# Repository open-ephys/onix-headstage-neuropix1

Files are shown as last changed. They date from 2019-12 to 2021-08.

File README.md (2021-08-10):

# ONIX Neuropixels-1.0 Headstage
Serialized, multifunction headstage targeting the [Neuropixels 1.0
probe](https://www.neuropixels.org/probe). This headstage supports:

- Two Neuropixels 1.0 probes
- A BNO055 9-axis IMU for real-time, 3D orientation tracking
- Three TS4231 light to digital converters for real-time, 3D position tracking
  with HTC Vive base stations
- A high performance MAX10 FPGA for real-time processing and probe data
  correction (offset removal and gain correction)

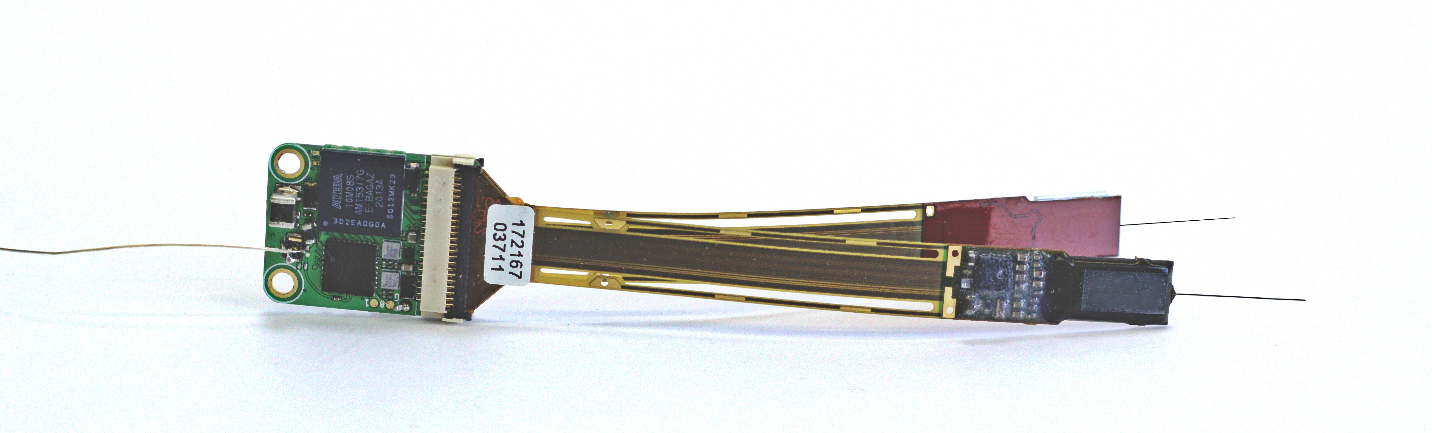
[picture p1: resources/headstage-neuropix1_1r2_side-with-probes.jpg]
headstage-neuropix1 revision 1.2


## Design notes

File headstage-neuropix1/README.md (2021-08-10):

# Design Files

## Standard vs.large
There are two versions of this headstage in this repository, one that uses the
standard IMEC-specified ZIF connector and a second that uses a larger, more
reliable one.

## Production
This folder contains panelized versions of both designs.

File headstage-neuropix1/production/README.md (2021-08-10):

# Production Files
These files are panelized versions of both large and standard ZIF connector
variants of the Neuropixels 1.0 Headstage. They were provided by [Speedy
Circuits](https://www.speedy-circuits.com.tw/).

- TOP, L#, BOT: Copper layers
- VIP: Via in pad
- PTH: Plated through hole
- NPTH: Non-plated through hole
- OUT: Outline
- \*SILK: Silkscreen
- \*PASTE: Stencil

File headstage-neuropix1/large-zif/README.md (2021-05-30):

# headstage-neuropix (large ZIF)
This version of the headstage has a larger, more reliable ZIF connector.

## Bill of materials
The bill of materials is located here: https://docs.google.com/spreadsheets/d/1dWKHe0VTVimXe6pwDThY2RrQNF4wLWle7LTdl6iC_KU/edit?usp=sharing

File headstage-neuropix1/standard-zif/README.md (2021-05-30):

# headstage-neuropix (standard ZIF)
This version of the headstage uses the IMEC-specified ZIF connector.

## Bill of materials
The bill of materials is located here: https://docs.google.com/spreadsheets/d/1dWKHe0VTVimXe6pwDThY2RrQNF4wLWle7LTdl6iC_KU/edit?usp=sharing

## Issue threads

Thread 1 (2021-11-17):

MAX4945 might be the wrong choice for this design

jonnew, 2021-11-17:
MAX4945 is an under/overvoltage lockout circuit used to protect the headstage. It turns on with the range 4.15 to 5.8V, which seems perfect. But there is an interesting issue that occurs when using a long and thin tether. Because of the series resistance of the tether, the voltage under no load needs to be quite high (e.g. like 7.5V). This way when the headstage starts to draw current and voltage is dropped on the tether, it settles at 5 or so volts at the headstage input. However, when using the MAX4945, 7.5V is too high for the headstage to ever turn on and we enter a deadlock. Choosing a version of this chip with a much wider range is probably a good idea (e.g. MAX4943 which has 7.4V overvoltage lockout) or it might just need to be bypassed. Alternatively, lower DC resistance tethers can be used (e.g. like the ones on the miniscope).

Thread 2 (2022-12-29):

Incompatibility between Photodiode index 0 and address 256

filcarv, 2022-12-29:
Photodiode 0 doesn't work reliably when using the NP in the nearest socket.

I don't see users using two probes with free-moving animals, so we can tell users to use the other socket for freely-moving animals.

This table of tests shows that Photodiode 0 (PD0) doesn't work reliably for some scenarios.

|Plugged<br />257 | Plugged<br />256 | Stream<br />257 | Stream<br />256 | Bonsai<br />257 | Bonsai<br />256 | PD0
|-- | -- | -- | -- | -- | -- | --
|Yes | Yes | True | - | Enabled | Disabled | ✅
|Yes | - | True | - | Enabled | Disabled | ✅
|- | Yes | - | True | Disabled | Enabled | 🗑️
|Yes | Yes | True | False | Enabled | Enabled | 🗑️

🗑️ - The data is garbage, and can’t be trusted. It still sends events even if the IR is not present.

jonnew, 2022-12-30:
Thanks for the detailed report. This behavior is similar to an issue on the headstage-64 rev. 1.3 where the routing of the un-amplified photodiode (PD) signal passes under the BNO055 and is corrupted in the process. Even in revision 1.3b, where the PD traces pass under the BNO055 on a different layer, with ground plane in between the them and the BNO055, it does not function. These traces are obviously very sensitive to stray electric fields from digital processes around them. I have a feeling that some of the traces coming back from the neuropixels' parallel-serial bus (PSB) are doing exactly the same thing. This makes sense given that the TS4231 receiver is quite far from the PD. If we redesign this headstage, extreme caution will be used when laying out the un-amplified PD  traces. Further, a guard ring can be employed to prevent leakage currents through the solder-mask.

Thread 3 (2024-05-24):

Gateware issues

jonnew, 2024-05-24:
Testing of these devices seems to be revealing intermittent issues in the gateware:

1. One channel in 384 of both the LFP and Spike streams always seems to produce 0 values. This value appears in the first frame of a superframe, but its position changes between resets. Aside from the obviously incorrect value, the location switch leads to a lack of confidence in a consistent channel mapping between runs
2. The hub clock is placed at the end of the frame which is at least non-conventional
3. The sync words are included in the data frame, but are not used
4. The amplifier data is non-contiguous and should be reordered in the gateware to remove counter and reserved segments
5. The Q11.5 -> Q11 conversion should be done on the FPGA instead of packing fixed point values into the frame for no reason (10 bit ADC determines sample resolution, the extra 5 bits are useless)

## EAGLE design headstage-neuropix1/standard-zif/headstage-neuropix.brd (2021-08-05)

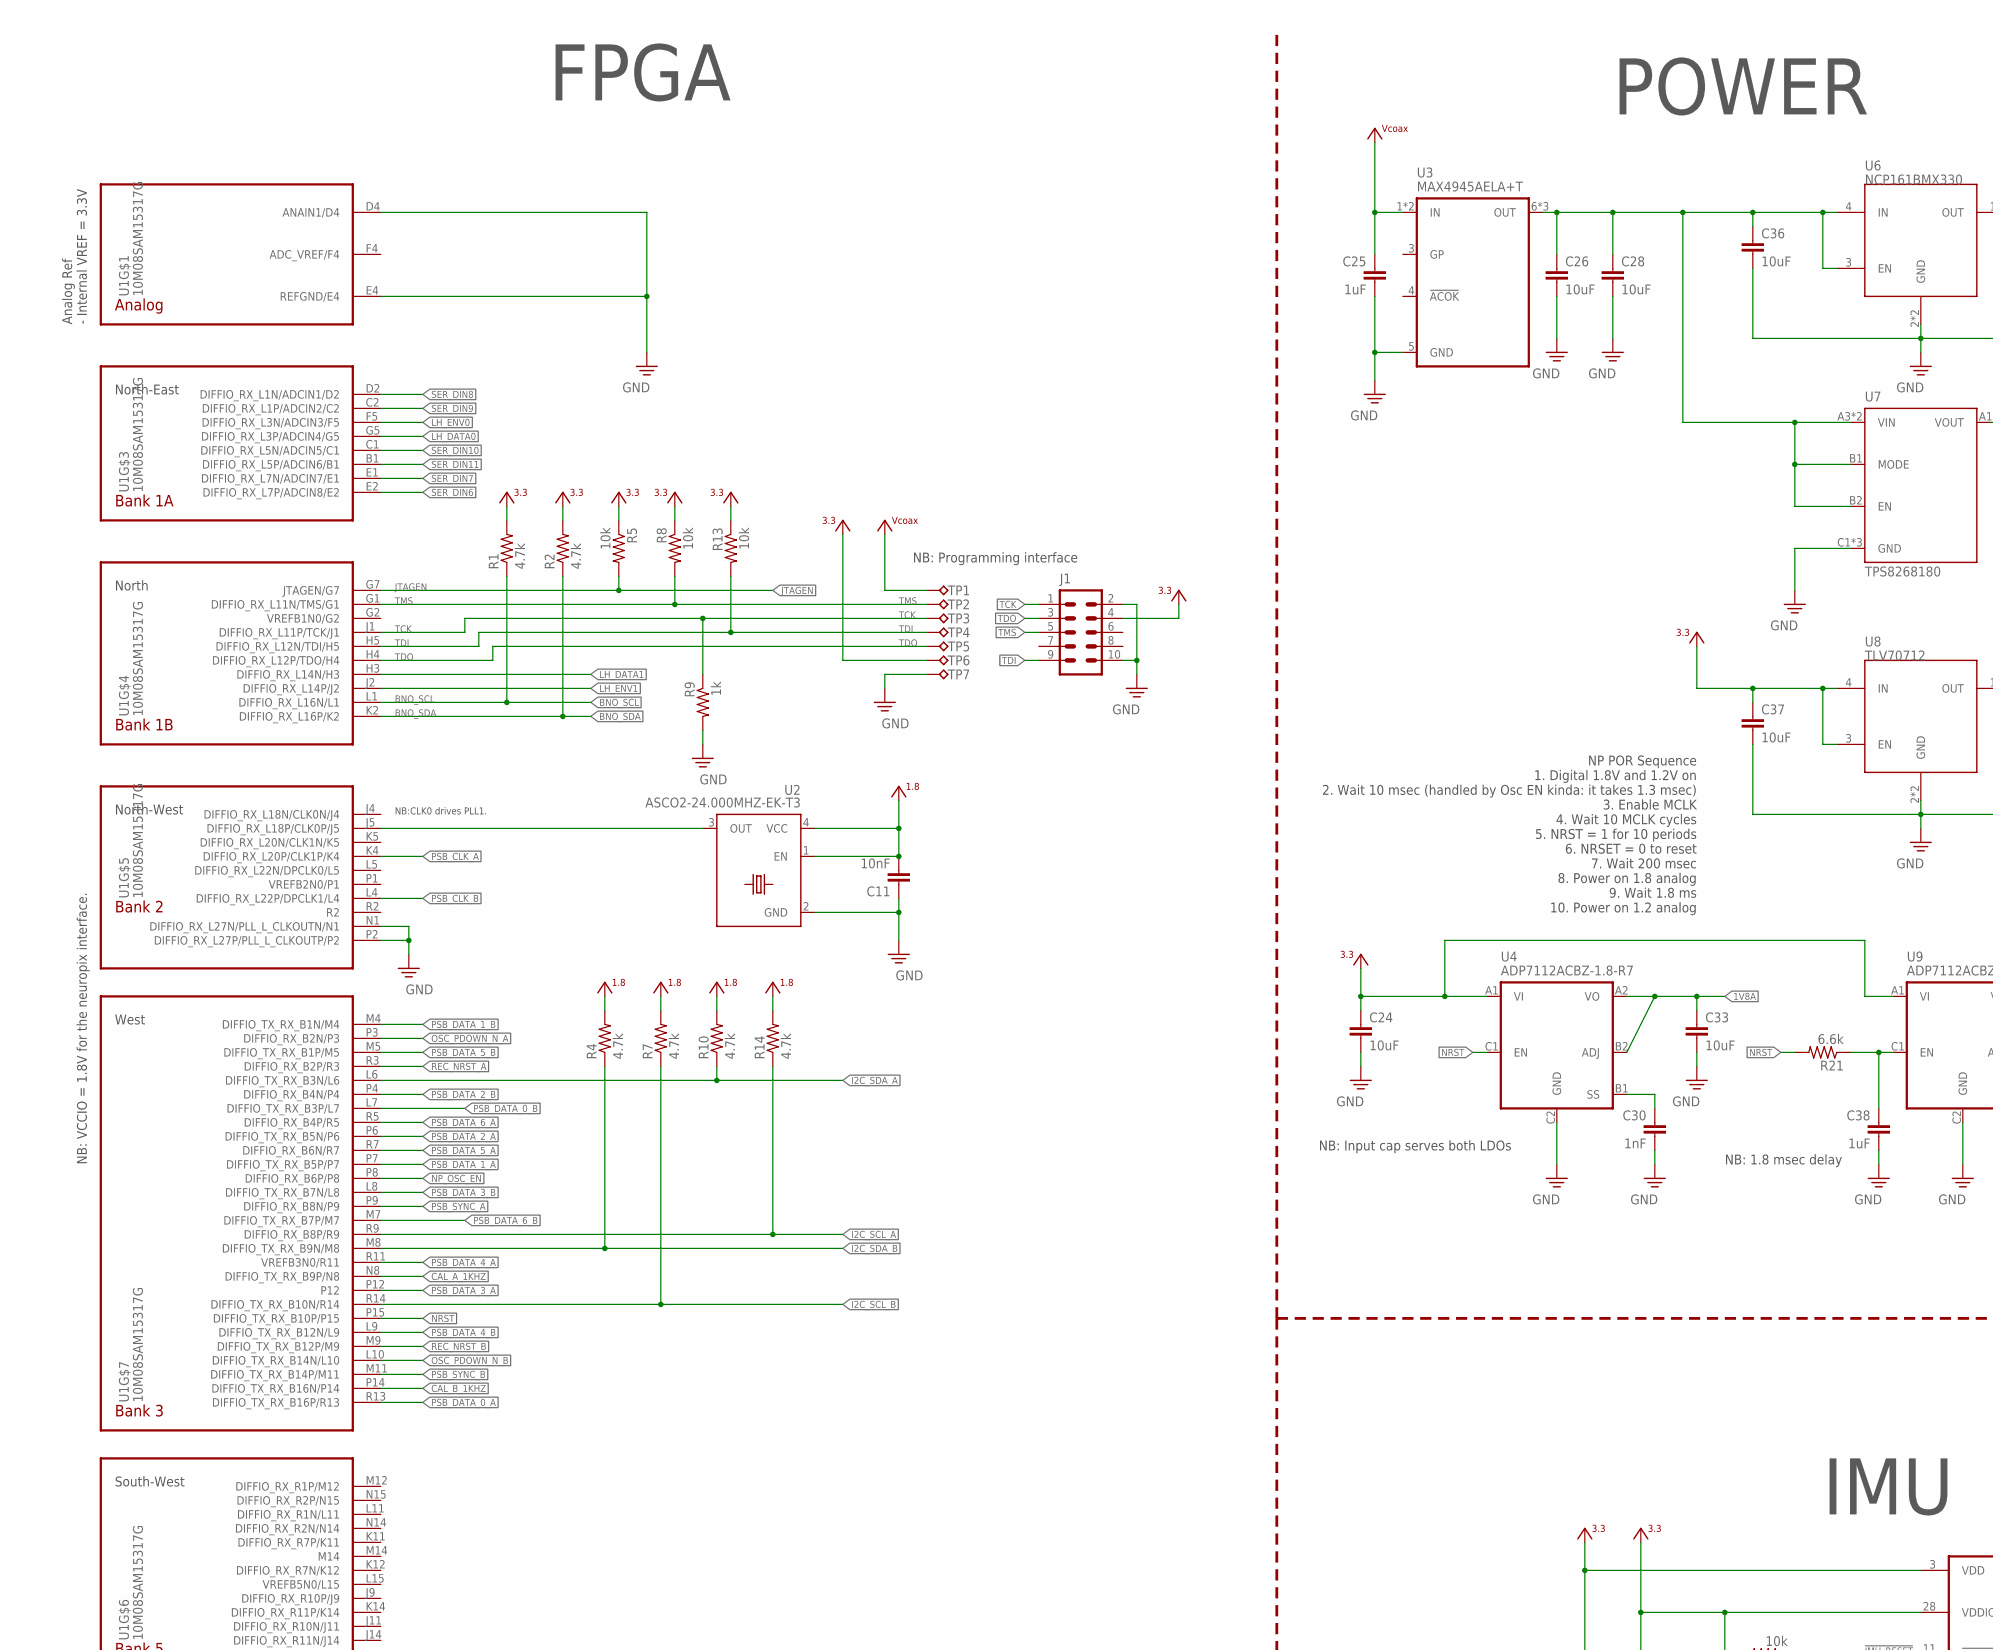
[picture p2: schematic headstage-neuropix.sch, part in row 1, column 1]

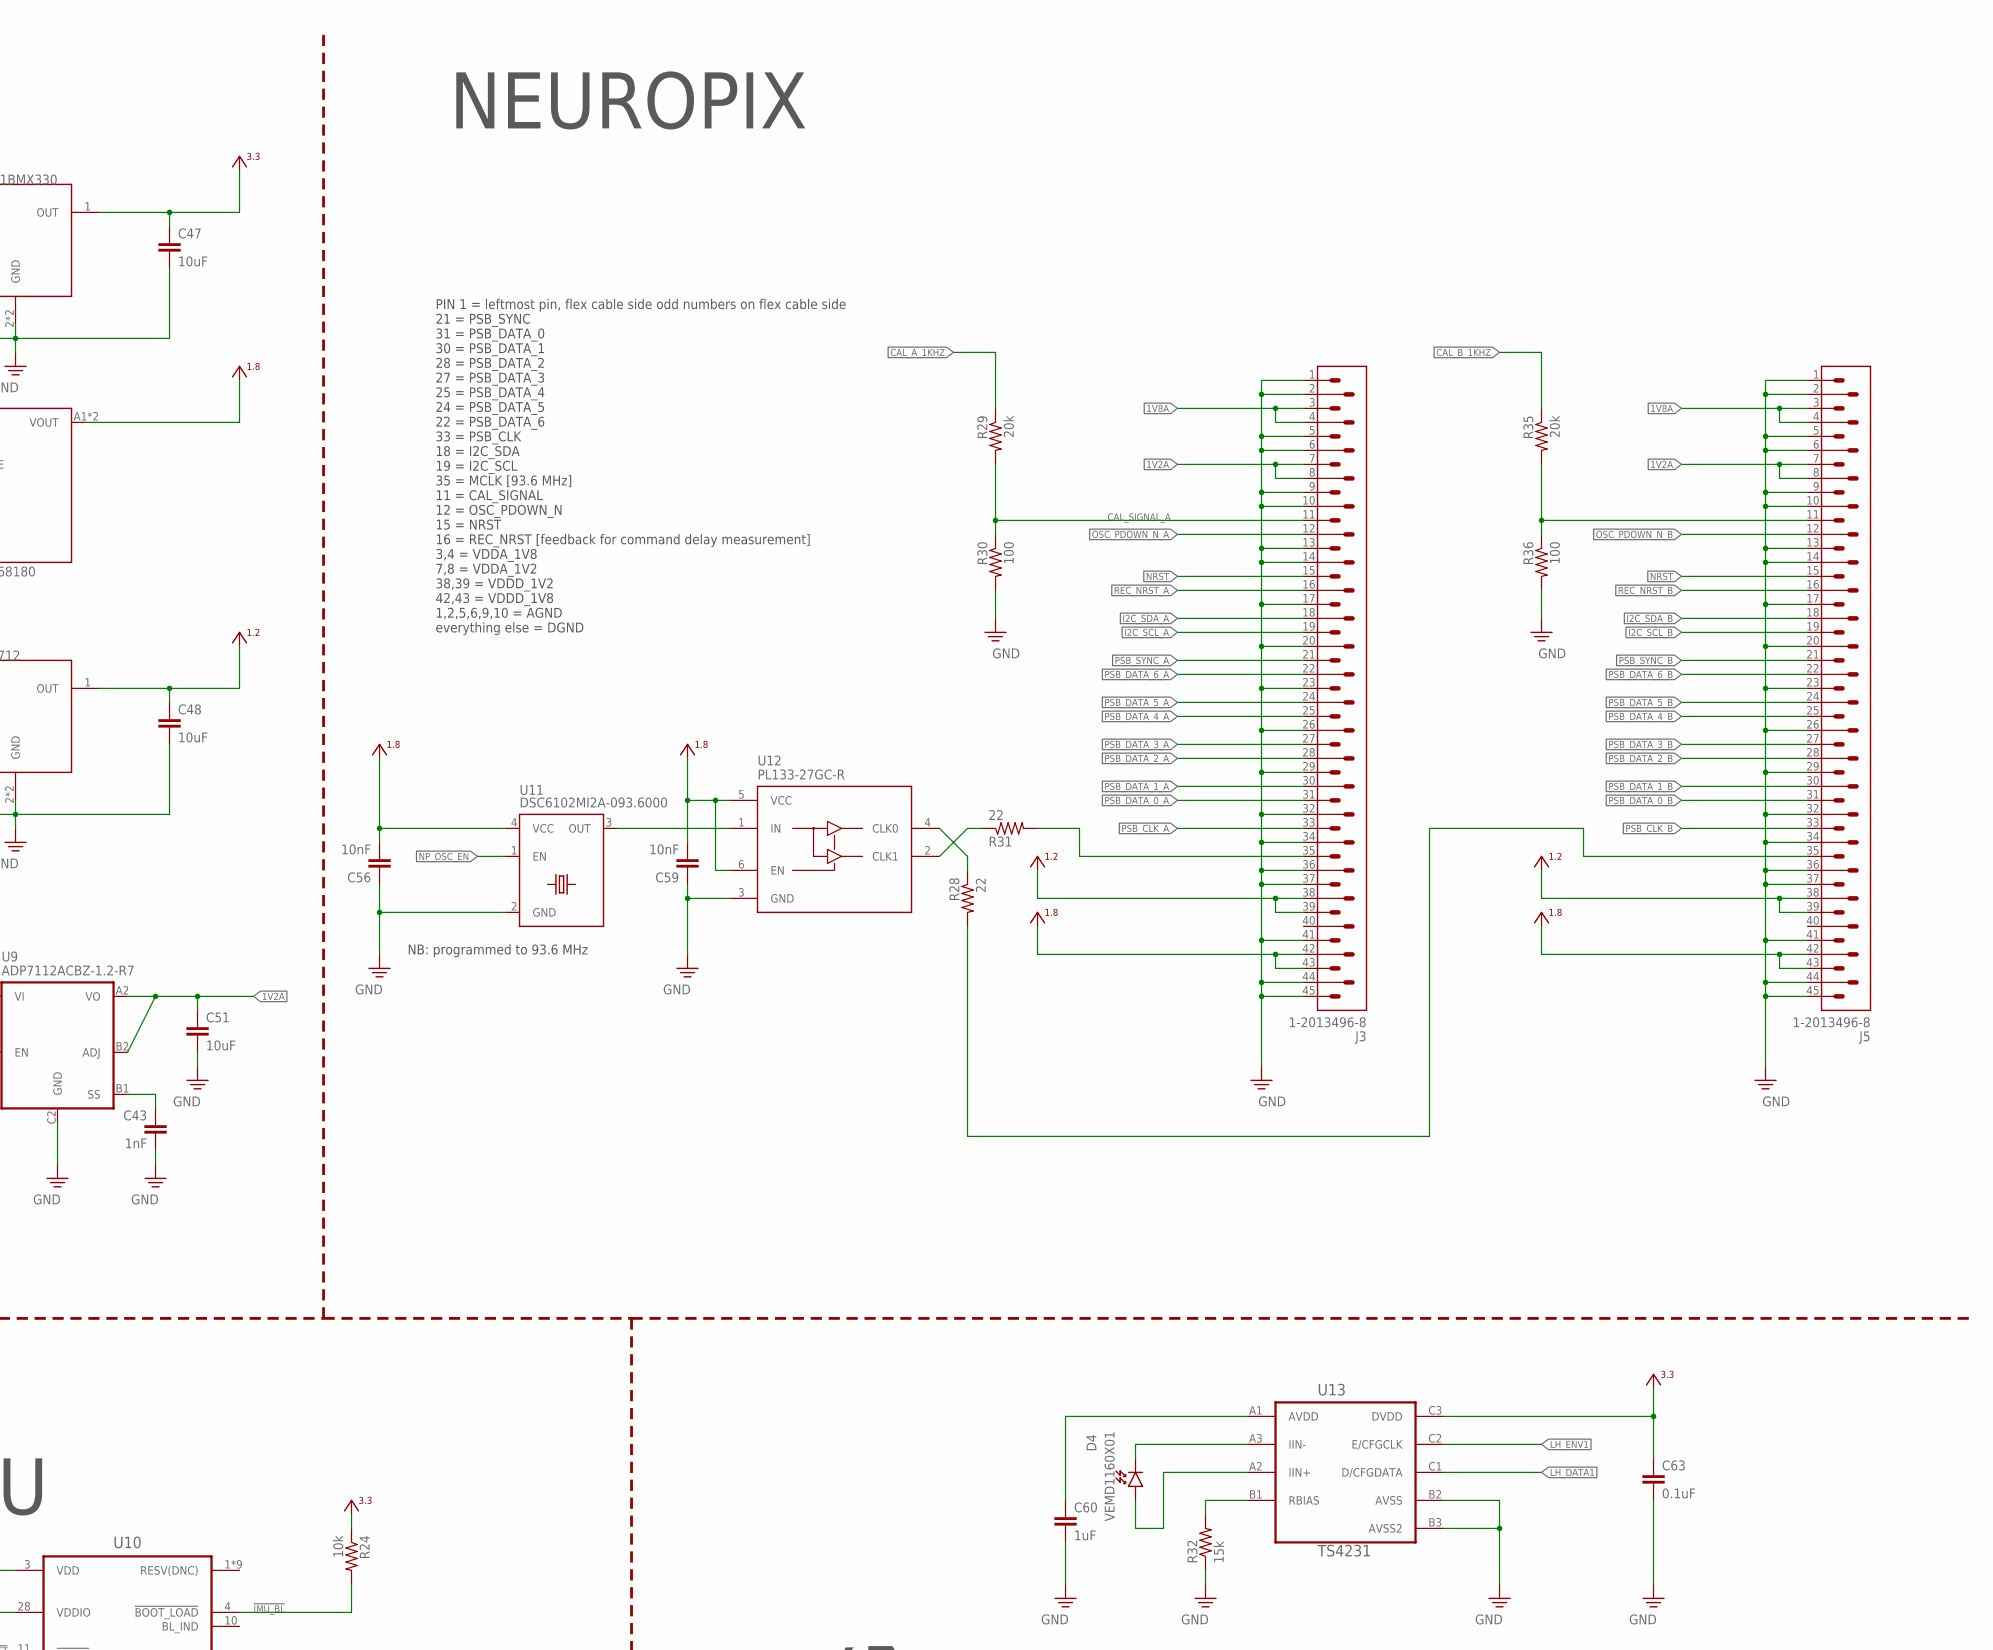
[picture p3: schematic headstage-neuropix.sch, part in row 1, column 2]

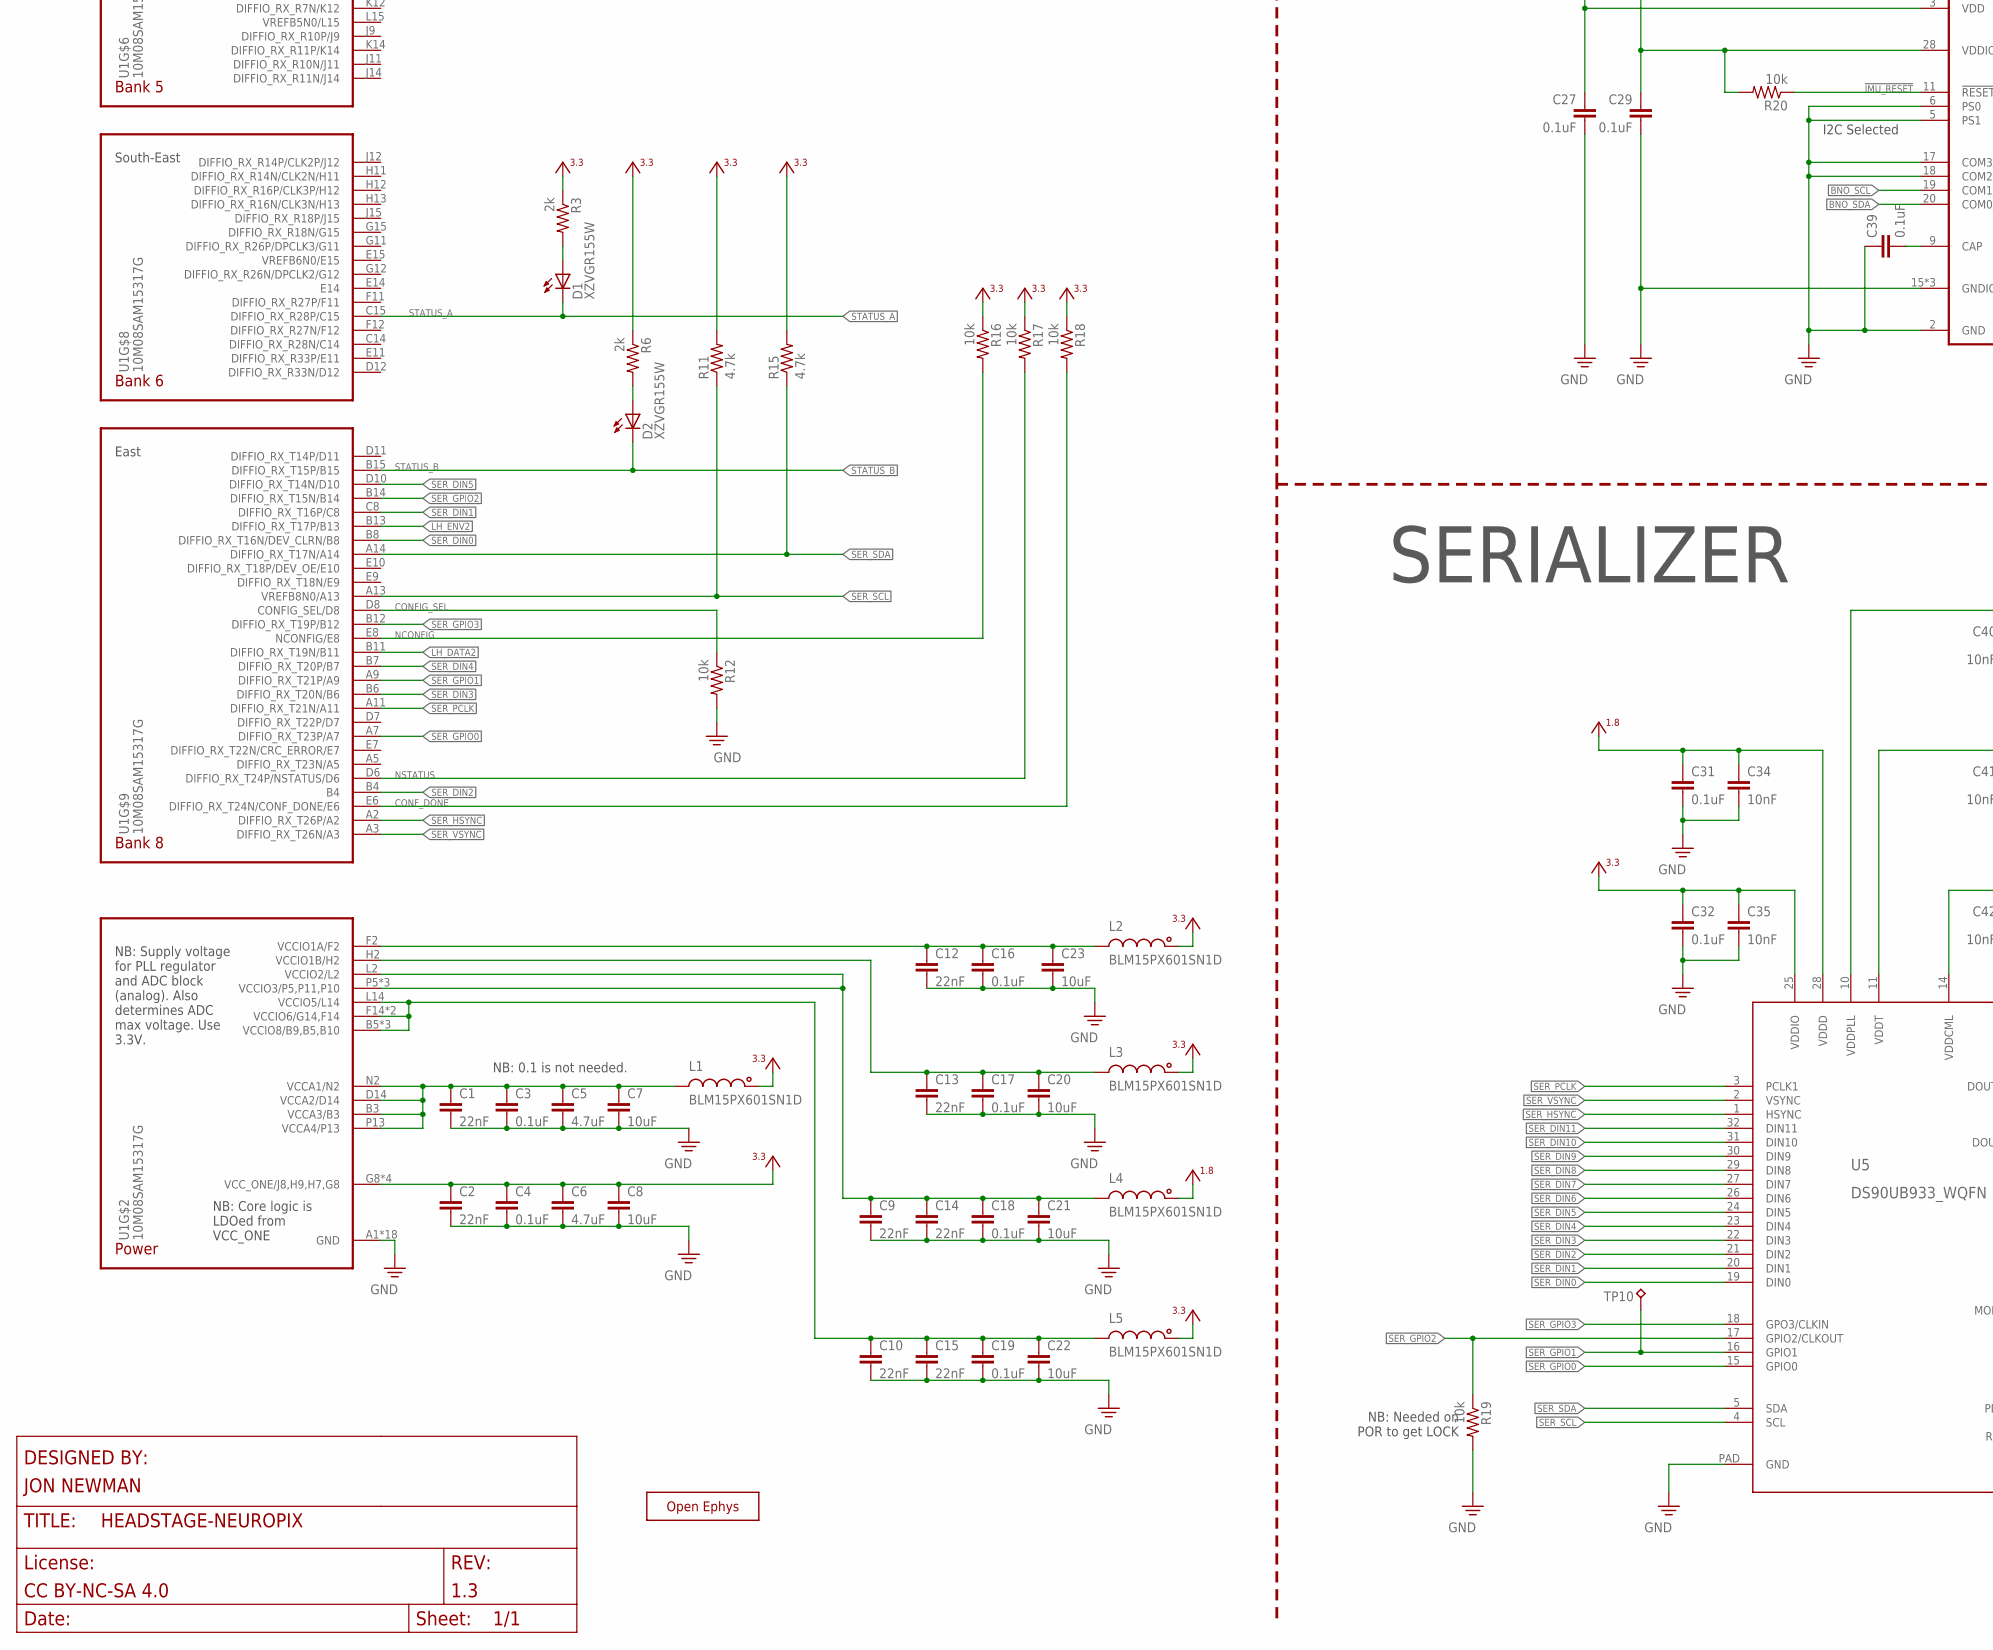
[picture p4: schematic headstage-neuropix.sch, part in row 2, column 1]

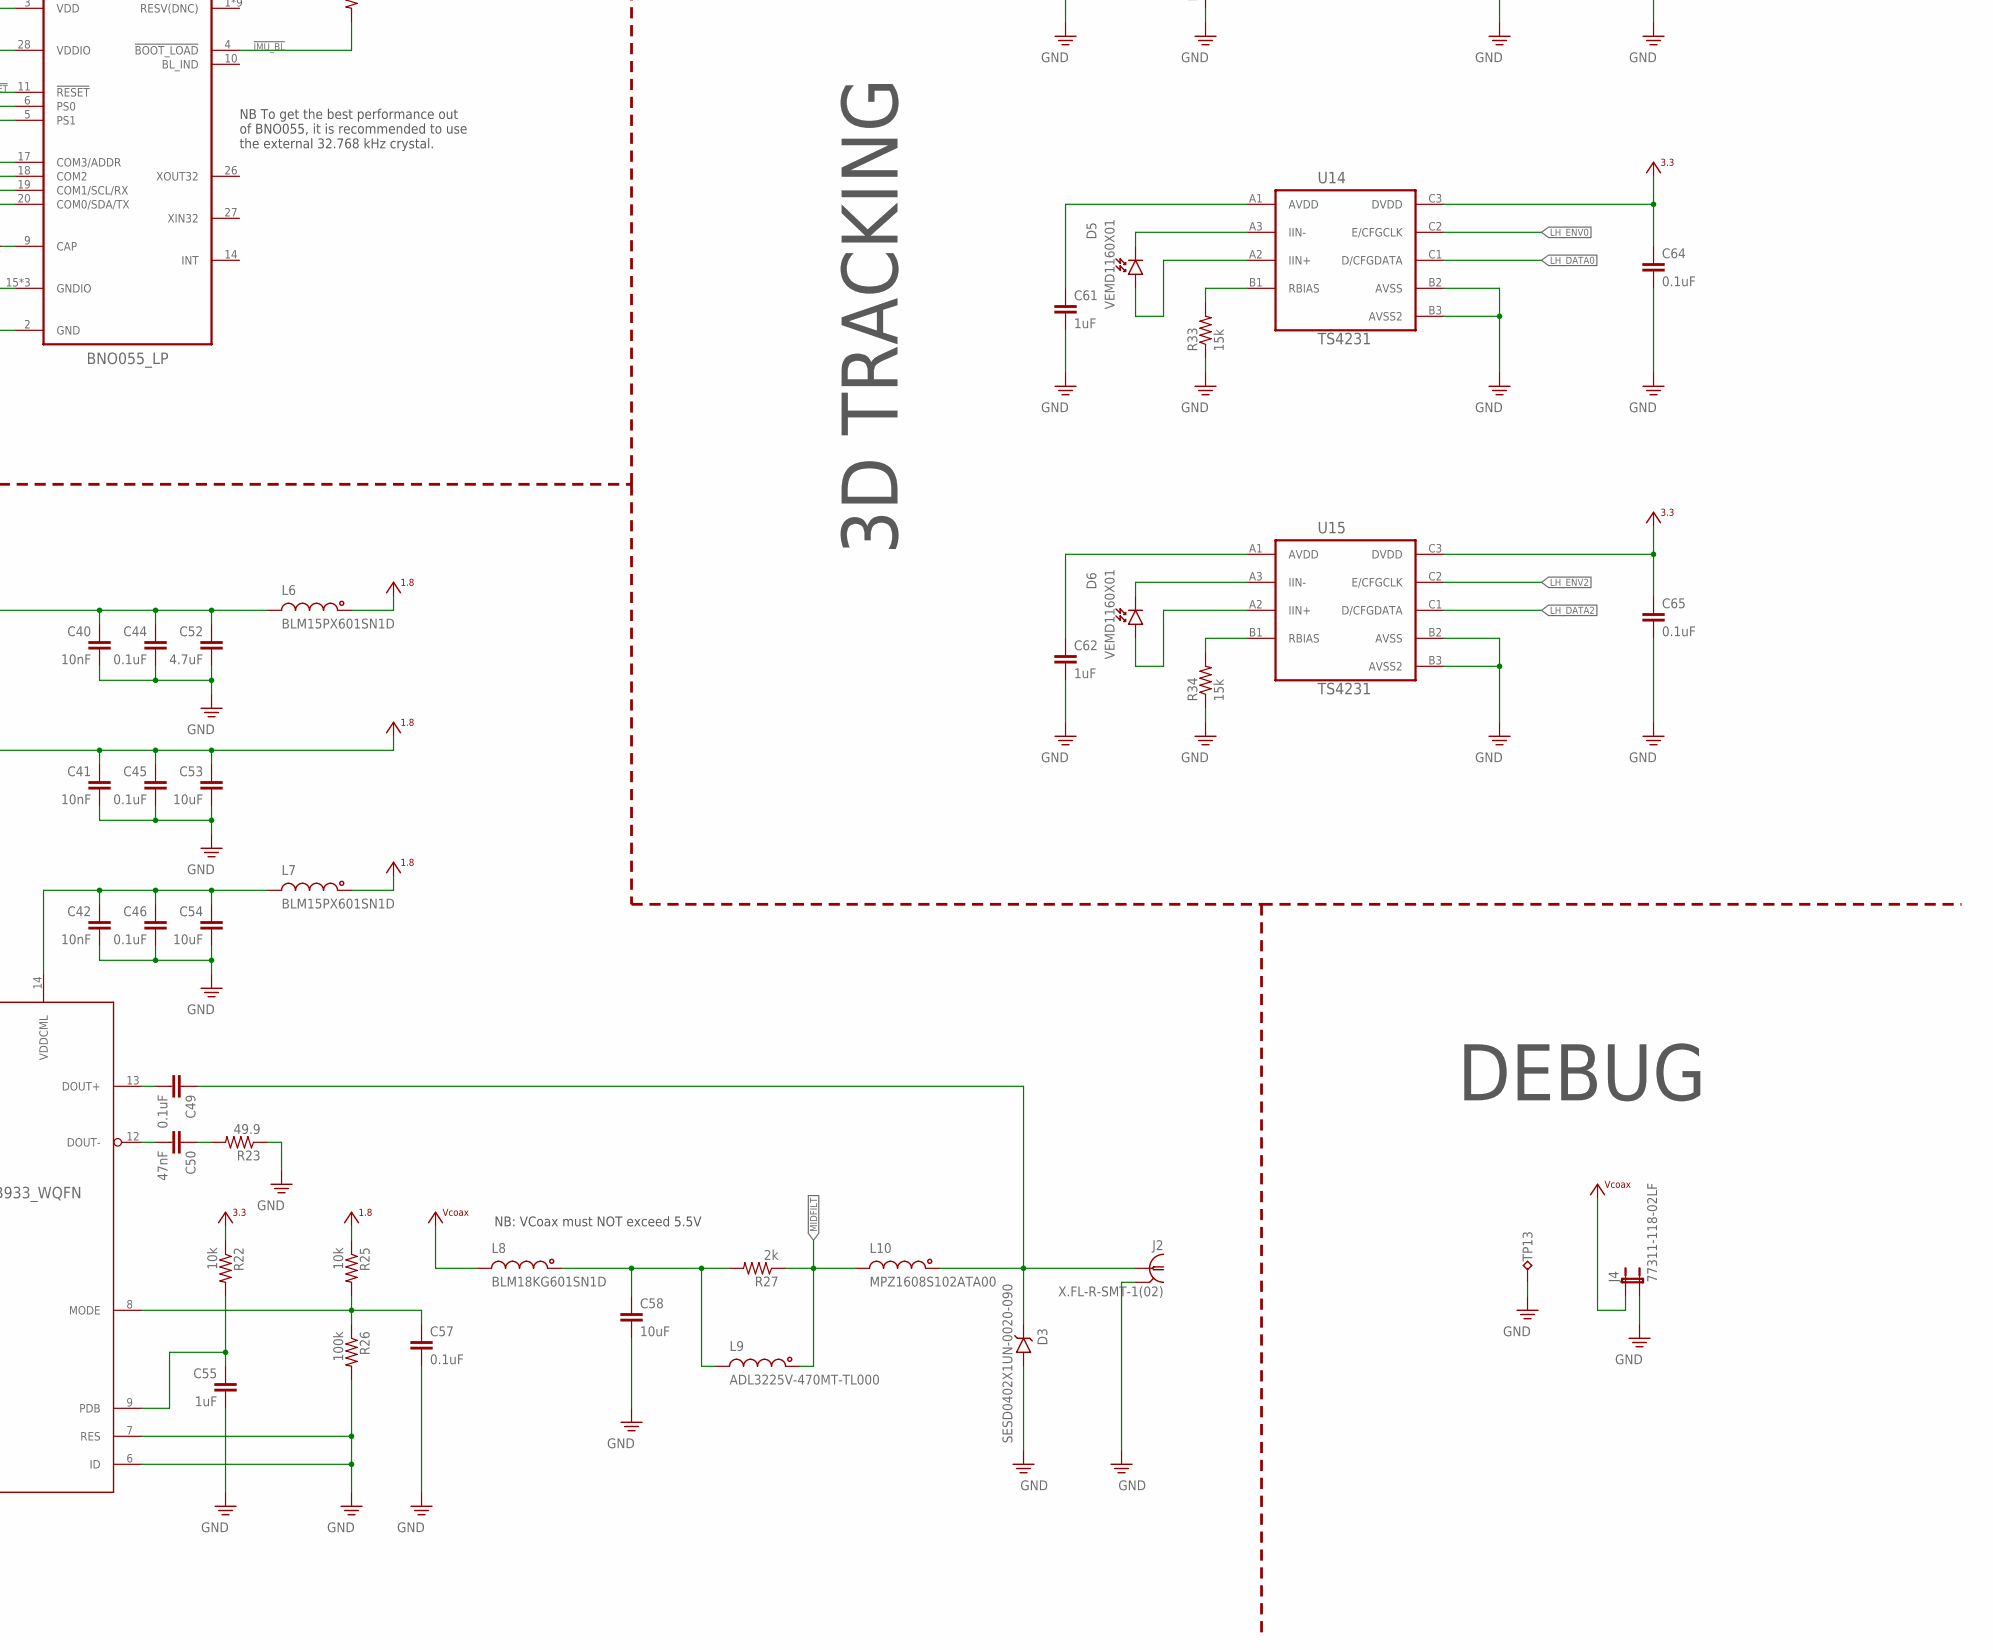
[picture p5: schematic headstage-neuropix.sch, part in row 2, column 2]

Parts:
C1, C2, C9, C10, C12, C13, C14, C15: 22nF; 0201T
C3, C4, C16, C17, C18, C19, C27, C29, C31, C32, C39, C44, C45, C46, C49, C57: 0.1uF; 0201T
C5, C6, C52: 4.7uF; 0402T
C7, C8, C20, C21, C22, C23, C53, C58: 10uF; 0402T
C11, C34, C35, C40, C41, C42, C56, C59: 10nF; 0201T
C24, C26, C28, C33, C36, C37, C47, C48, C51, C54: 10uF; 0402TW
C25, C38, C55: 1uF; 0201T
C30, C43: 1nF; 0201T
C50: 47nF; 0201T
C60, C61, C62: 1uF; 0201T; PARTNO CL03A105MP3ZSNH
C63, C64, C65: 0.1uF; 0201T; PARTNO C0603X5R1C104K030BC
D1, D2: XZVGR155W; LED-0201T
D3: SESD0402X1UN-0020-090; 0402T-DFN
D4, D5, D6: VEMD1160X01; 0805PT-NOSILK
J1: 302-S101; 2X05_IDC
J2: X.FL-R-SMT-1(02); X_FL_R_SMT_1(02)
J3, J5: 1-2013496-8
J4: 77311-118-02LF; JP2
L1, L2, L3, L4, L5, L6, L7: BLM15PX601SN1D; 0402T
L8: BLM18KG601SN1D; 0603T
L9: ADL3225V-470MT-TL000; 1210T
L10: MPZ1608S102ATA00; 0603T
R1, R2, R4, R7, R10, R11, R14, R15: 4.7k; 0201T
R3, R6, R27: 2k; 0201T
R5, R8, R12, R13, R16, R17, R18, R19, R20, R22, R24, R25: 10k; 0201T
R9: 1k; 0201T
R21: 6.6k; 0201T
R23: 49.9; 0201T
R26: 100k; 0201T
R28, R31: 22; 0201T
R29, R35: 20k; 0201T
R30, R36: 100; 0201T
R32, R33, R34: 15k; 0201T
TP1, TP2, TP3, TP4, TP5, TP6, TP7: TPTP10R; TP10R
TP10: TPTP09R; TP09R
TP13: TPTP20R; TP20R
U1: 10M08SAM15317G; MBGA153-8X8
U2: ASCO2-24.000MHZ-EK-T3; ASCO
U3: MAX4945AELA+T; UDFN8-2X2
U4: ADP7112ACBZ-1.8-R7; WLCSP6-1X1.2-LP
U5: DS90UB933_WQFN; WQFN32-5X5-LP
U6: NCP161BMX330; X2SON
U7: TPS8268180; MICROSIP9-3X2.3
U8: TLV70712; X2SON
U9: ADP7112ACBZ-1.2-R7; WLCSP6-1X1.2-LP
U10: BNO055_LP; LGA-28-3.8X2.5-LP
U11: DSC6102MI2A-093.6000; VFLGA4-2.0X1.6
U12: PL133-27GC-R; DFN6_2X1.3_PAD
U13, U14, U15: TS4231; WLCSP3X3
X2: OE-LOGO_14X10; OE-LOGO-14X10

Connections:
1V2A: C51.1, J3.7, J3.8, J5.7, J5.8, U9.A2 (VO), U9.B2 (ADJ)
1V8A: C33.1, J3.3, J3.4, J5.3, J5.4, U4.A2 (VO), U4.B2 (ADJ)
24MHZ_P: U1.J5 (DIFFIO_RX_L18P/CLK0P/J5), U2.3 (OUT)
!IMU_BL: R24.2, U10.4 (!BOOT_LOAD)
!IMU_RESET: R20.1, U10.11 (!RESET)
+1V2: C48.1, J3.38, J3.39, J5.38, J5.39, U8.1 (OUT)
+1V8: C11.2, C31.1, C34.1, C41.1, C45.1, C53.1, C56.2, C59.2, J3.42, J3.43, J5.42, J5.43, L4.1, L6.1, L7.1, R4.2, R7.2, R10.2, R14.2, R25.1, U2.1 (EN), U2.4 (VCC), U5.11 (VDDT), U5.28 (VDDD), U7.A1 (VOUT), U7.A2 (VOUT), U11.4 (VCC), U12.5 (VCC), U12.6 (EN)
+3V3: C2.1, C4.1, C6.1, C8.1, C24.1, C27.1, C29.1, C32.1, C35.1, C37.1, C47.1, C63.1, C64.1, C65.1, J1.4, L1.1, L2.1, L3.1, L5.1, R1.2, R2.2, R3.1, R5.1, R6.1, R8.1, R11.2, R13.1, R15.2, R16.1, R17.1, R18.1, R20.2, R22.1, R24.1, TP6.TP, U1.G8 (VCC_ONE/J8,H9,H7,G8), U1.H7 (VCC_ONE/J8,H9,H7,G8), U1.H9 (VCC_ONE/J8,H9,H7,G8), U1.J8 (VCC_ONE/J8,H9,H7,G8), U4.A1 (VI), U5.25 (VDDIO), U6.1 (OUT), U8.3 (EN), U8.4 (IN), U9.A1 (VI), U10.3 (VDD), U10.28 (VDDIO), U13.C3 (DVDD), U14.C3 (DVDD), U15.C3 (DVDD)
BNO_SCL: R1.1, U1.L1 (DIFFIO_RX_L16N/L1), U10.19 (COM1/SCL/RX)
BNO_SDA: R2.1, U1.K2 (DIFFIO_RX_L16P/K2), U10.20 (COM0/SDA/TX)
CAL_A_1KHZ: R29.1, U1.N8 (DIFFIO_TX_RX_B9P/N8)
CAL_B_1KHZ: R35.1, U1.P14 (DIFFIO_TX_RX_B16N/P14)
CAL_SIGNAL_A: J3.11, R29.2, R30.1
CAL_SIGNAL_A1: J5.11, R35.2, R36.1
CONFIG_SEL: R12.1, U1.D8 (CONFIG_SEL/D8)
CONF_DONE: R18.2, U1.E6 (DIFFIO_RX_T24N/CONF_DONE/E6)
GND: C1.2, C2.2, C3.2, C4.2, C5.2, C6.2, C7.2, C8.2, C9.2, C10.2, C11.1, C12.2, C13.2, C14.2, C15.2, C16.2, C17.2, C18.2, C19.2, C20.2, C21.2, C22.2, C23.2, C24.2, C25.2, C26.2, C27.2, C28.2, C29.2, C30.2, C31.2, C32.2, C33.2, C34.2, C35.2, C36.2, C37.2, C38.2, C39.1, C40.2, C41.2, C42.2, C43.2, C44.2, C45.2, C46.2, C47.2, C48.2, C51.2, C52.2, C53.2, C54.2, C55.2, C56.1, C57.2, C58.2, C59.1, C60.2, C61.2, C62.2, C63.2, C64.2, C65.2, D3.A, J1.2, J1.10, J2.P$2 (2), J2.P$3 (2), J2.P$4 (2), J3.1, J3.2, J3.5, J3.6, J3.9, J3.10, J3.13, J3.14, J3.17, J3.20, J3.23, J3.26, J3.29, J3.32, J3.34, J3.36, J3.37, J3.41, J3.44, J3.45, J4.2, J5.1, J5.2, J5.5, J5.6, J5.9, J5.10, J5.13, J5.14, J5.17, J5.20, J5.23, J5.26, J5.29, J5.32, J5.34, J5.36, J5.37, J5.41, J5.44, J5.45, R9.2, R12.2, R19.2, R23.1, R26.2, R30.2, R32.1, R33.1, R34.1, R36.2, TP7.TP, TP13.TP, U1.A1 (GND), U1.A15 (GND), U1.B2 (GND), U1.D4 (ANAIN1/D4), U1.D5 (GND), U1.D9 (GND), U1.E4 (REFGND/E4), U1.E5 (GND), U1.E12 (GND), U1.G4 (GND), U1.G9 (GND), U1.H8 (GND), U1.H14 (GND), U1.J7 (GND), U1.L12 (GND), U1.M2 (GND), U1.M6 (GND), U1.M10 (GND), U1.N1 (DIFFIO_RX_L27N/PLL_L_CLKOUTN/N1), U1.P2 (DIFFIO_RX_L27P/PLL_L_CLKOUTP/P2), U1.R1 (GND), U1.R15 (GND), U2.2 (GND), U3.5 (GND), U4.C2 (GND), U5.6 (ID), U5.7 (RES), U5.PAD (GND), U6.2 (GND), U6.PAD (GND), U7.C1 (GND), U7.C2 (GND), U7.C3 (GND), U8.2 (GND), U8.PAD (GND), U9.C2 (GND), U10.2 (GND), U10.5 (PS1), U10.6 (PS0), U10.15 (GNDIO), U10.16 (GNDIO), U10.17 (COM3/ADDR), U10.18 (COM2), U10.25 (GNDIO), U11.2 (GND), U12.3 (GND), U13.B2 (AVSS), U13.B3 (AVSS2), U14.B2 (AVSS), U14.B3 (AVSS2), U15.B2 (AVSS), U15.B3 (AVSS2)
I2C_SCL_A: J3.19, R14.1, U1.R9 (DIFFIO_RX_B8P/R9)
I2C_SCL_B: J5.19, R7.1, U1.R14 (DIFFIO_TX_RX_B10N/R14)
I2C_SDA_A: J3.18, R10.1, U1.L6 (DIFFIO_TX_RX_B3N/L6)
I2C_SDA_B: J5.18, R4.1, U1.M8 (DIFFIO_TX_RX_B9N/M8)
JTAGEN: R5.2, U1.G7 (JTAGEN/G7)
LH_DATA0: U1.G5 (DIFFIO_RX_L3P/ADCIN4/G5), U14.C1 (D/CFGDATA)
LH_DATA1: U1.H3 (DIFFIO_RX_L14N/H3), U13.C1 (D/CFGDATA)
LH_DATA2: U1.B11 (DIFFIO_RX_T19N/B11), U15.C1 (D/CFGDATA)
LH_ENV0: U1.F5 (DIFFIO_RX_L3N/ADCIN3/F5), U14.C2 (E/CFGCLK)
LH_ENV1: U1.J2 (DIFFIO_RX_L14P/J2), U13.C2 (E/CFGCLK)
LH_ENV2: U1.B13 (DIFFIO_RX_T17P/B13), U15.C2 (E/CFGCLK)
MIDFILT: L9.1, L10.2, R27.1
unnamed: U11.3 (OUT), U12.1 (IN)
unnamed: R28.1, U12.4 (CLK0)
unnamed: J3.35, R31.2
unnamed: C13.1, C17.1, C20.1, L3.2, U1.H2 (VCCIO1B/H2)
unnamed: J5.35, R28.2
unnamed: R31.1, U12.2 (CLK1)
unnamed: D4.C, U13.A3 (IIN-)
unnamed: D4.A, U13.A2 (IIN+)
unnamed: R32.2, U13.B1 (RBIAS)
unnamed: C60.1, U13.A1 (AVDD)
unnamed: C58.1, L8.1, L9.2, R27.2
unnamed: D5.C, U14.A3 (IIN-)
unnamed: D5.A, U14.A2 (IIN+)
unnamed: R33.2, U14.B1 (RBIAS)
unnamed: D6.C, U15.A3 (IIN-)
unnamed: D6.A, U15.A2 (IIN+)
unnamed: C49.2, U5.13 (DOUT+)
unnamed: R34.2, U15.B1 (RBIAS)
unnamed: C55.1, R22.2, U5.9 (PDB)
unnamed: C50.2, U5.12 (DOUT-)
unnamed: C50.1, R23.2
unnamed: C57.1, R25.2, R26.1, U5.8 (MODE)
unnamed: C40.1, C44.1, C52.1, L6.2, U5.10 (VDDPLL)
unnamed: C42.1, C46.1, C54.1, L7.2, U5.14 (VDDCML)
unnamed: C61.1, U14.A1 (AVDD)
unnamed: C62.1, U15.A1 (AVDD)
unnamed: C26.1, C28.1, C36.1, U3.6 (OUT), U3.7 (OUT), U3.8 (OUT), U6.3 (EN), U6.4 (IN), U7.A3 (VIN), U7.B1 (MODE), U7.B2 (EN), U7.B3 (VIN)
unnamed: C30.1, U4.B1 (SS)
unnamed: C43.1, U9.B1 (SS)
unnamed: C38.1, R21.1, U9.C1 (EN)
unnamed: C39.2, U10.9 (CAP)
unnamed: D2.2 (A), R6.2
unnamed: D1.2 (A), R3.2
NCONFIG: R16.2, U1.E8 (NCONFIG/E8)
NP_OSC_EN: U1.P8 (DIFFIO_RX_B6P/P8), U11.1 (EN)
NRST: J3.15, J5.15, R21.2, U1.P15 (DIFFIO_TX_RX_B10P/P15), U4.C1 (EN)
NSTATUS: R17.2, U1.D6 (DIFFIO_RX_T24P/NSTATUS/D6)
OSC_PDOWN_N_A: J3.12, U1.P3 (DIFFIO_RX_B2N/P3)
OSC_PDOWN_N_B: J5.12, U1.L10 (DIFFIO_TX_RX_B14N/L10)
PSB_CLK_A: J3.33, U1.K4 (DIFFIO_RX_L20P/CLK1P/K4)
PSB_CLK_B: J5.33, U1.L4 (DIFFIO_RX_L22P/DPCLK1/L4)
PSB_DATA_0_A: J3.31, U1.R13 (DIFFIO_TX_RX_B16P/R13)
PSB_DATA_0_B: J5.31, U1.L7 (DIFFIO_TX_RX_B3P/L7)
PSB_DATA_1_A: J3.30, U1.P7 (DIFFIO_TX_RX_B5P/P7)
PSB_DATA_1_B: J5.30, U1.M4 (DIFFIO_TX_RX_B1N/M4)
PSB_DATA_2_A: J3.28, U1.P6 (DIFFIO_TX_RX_B5N/P6)
PSB_DATA_2_B: J5.28, U1.P4 (DIFFIO_RX_B4N/P4)
PSB_DATA_3_A: J3.27, U1.P12
PSB_DATA_3_B: J5.27, U1.L8 (DIFFIO_TX_RX_B7N/L8)
PSB_DATA_4_A: J3.25, U1.R11 (VREFB3N0/R11)
PSB_DATA_4_B: J5.25, U1.L9 (DIFFIO_TX_RX_B12N/L9)
PSB_DATA_5_A: J3.24, U1.R7 (DIFFIO_RX_B6N/R7)
PSB_DATA_5_B: J5.24, U1.M5 (DIFFIO_TX_RX_B1P/M5)
PSB_DATA_6_A: J3.22, U1.R5 (DIFFIO_RX_B4P/R5)
PSB_DATA_6_B: J5.22, U1.M7 (DIFFIO_TX_RX_B7P/M7)
PSB_SYNC_A: J3.21, U1.P9 (DIFFIO_RX_B8N/P9)
PSB_SYNC_B: J5.21, U1.M11 (DIFFIO_TX_RX_B14P/M11)
REC_NRST_A: J3.16, U1.R3 (DIFFIO_RX_B2P/R3)
REC_NRST_B: J5.16, U1.M9 (DIFFIO_TX_RX_B12P/M9)
SER_DIN0: U1.B8 (DIFFIO_RX_T16N/DEV_CLRN/B8), U5.19 (DIN0)
SER_DIN1: U1.C8 (DIFFIO_RX_T16P/C8), U5.20 (DIN1)
SER_DIN2: U1.B4, U5.21 (DIN2)
SER_DIN3: U1.B6 (DIFFIO_RX_T20N/B6), U5.22 (DIN3)
SER_DIN4: U1.B7 (DIFFIO_RX_T20P/B7), U5.23 (DIN4)
SER_DIN5: U1.D10 (DIFFIO_RX_T14N/D10), U5.24 (DIN5)
SER_DIN6: U1.E2 (DIFFIO_RX_L7P/ADCIN8/E2), U5.26 (DIN6)
SER_DIN7: U1.E1 (DIFFIO_RX_L7N/ADCIN7/E1), U5.27 (DIN7)
SER_DIN8: U1.D2 (DIFFIO_RX_L1N/ADCIN1/D2), U5.29 (DIN8)
SER_DIN9: U1.C2 (DIFFIO_RX_L1P/ADCIN2/C2), U5.30 (DIN9)
SER_DIN10: U1.C1 (DIFFIO_RX_L5N/ADCIN5/C1), U5.31 (DIN10)
SER_DIN11: U1.B1 (DIFFIO_RX_L5P/ADCIN6/B1), U5.32 (DIN11)
SER_GPIO0: U1.A7 (DIFFIO_RX_T23P/A7), U5.15 (GPIO0)
SER_GPIO1: TP10.TP, U1.A9 (DIFFIO_RX_T21P/A9), U5.16 (GPIO1)
SER_GPIO2: R19.1, U1.B14 (DIFFIO_RX_T15N/B14), U5.17 (GPIO2/CLKOUT)
SER_GPIO3: U1.B12 (DIFFIO_RX_T19P/B12), U5.18 (GPO3/CLKIN)
SER_HSYNC: U1.A2 (DIFFIO_RX_T26P/A2), U5.1 (HSYNC)
SER_PCLK: U1.A11 (DIFFIO_RX_T21N/A11), U5.3 (PCLK1)
SER_SCL: R11.1, U1.A13 (VREFB8N0/A13), U5.4 (SCL)
SER_SDA: R15.1, U1.A14 (DIFFIO_RX_T17N/A14), U5.5 (SDA)
SER_VSYNC: U1.A3 (DIFFIO_RX_T26N/A3), U5.2 (VSYNC)
SIGOUT: C49.1, D3.C, J2.P$1 (1), L10.1
STATUS_A: D1.1 (C), U1.C15 (DIFFIO_RX_R28P/C15)
STATUS_B: D2.1 (C), U1.B15 (DIFFIO_RX_T15P/B15)
TCK: J1.1, R9.1, TP3.TP, U1.J1 (DIFFIO_RX_L11P/TCK/J1)
TDI: J1.9, R13.2, TP4.TP, U1.H5 (DIFFIO_RX_L12N/TDI/H5)
TDO: J1.3, TP5.TP, U1.H4 (DIFFIO_RX_L12P/TDO/H4)
TMS: J1.5, R8.2, TP2.TP, U1.G1 (DIFFIO_RX_L11N/TMS/G1)
VCCA: C1.1, C3.1, C5.1, C7.1, L1.2, U1.B3 (VCCA3/B3), U1.D14 (VCCA2/D14), U1.N2 (VCCA1/N2), U1.P13 (VCCA4/P13)
VCCIO: C10.1, C15.1, C19.1, C22.1, L5.2, U1.B5 (VCCIO8/B9,B5,B10), U1.B9 (VCCIO8/B9,B5,B10), U1.B10 (VCCIO8/B9,B5,B10), U1.F14 (VCCIO6/G14,F14), U1.G14 (VCCIO6/G14,F14), U1.L14 (VCCIO5/L14)
VCCIO2: C9.1, C14.1, C18.1, C21.1, L4.2, U1.L2 (VCCIO2/L2), U1.P5 (VCCIO3/P5,P11,P10), U1.P10 (VCCIO3/P5,P11,P10), U1.P11 (VCCIO3/P5,P11,P10)
VCCIOA: C12.1, C16.1, C23.1, L2.2, U1.F2 (VCCIO1A/F2)
VCOAX: C25.1, J4.1, L8.2, TP1.TP, U3.1 (IN), U3.2 (IN)

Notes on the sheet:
NB: VCoax must NOT exceed 5.5V
SERIALIZER
POWER
NEUROPIX
DEBUG
PIN 1 = leftmost pin, flex cable side odd numbers on flex cable side 21 = PSB_SYNC 31 = PSB_DATA_0 30 = PSB_DATA_1 28 = PSB_DATA_2 27 = PSB_DATA_3 25 = PSB_DATA_4 24 = PSB_DATA_5 22 = PSB_DATA_6 33 = PSB_CLK 18 = I2C_SDA 19 = I2C_SCL 35 = MCLK [93.6 MHz] 11 = CAL_SIGNAL 12 = OSC_PDOWN_N 15 = NRST 1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
NB: Core logic is LDOed from VCC_ONE
NB: Supply voltage for PLL regulator and ADC block (analog). Also determines ADC max voltage. Use 3.3V.
NB: VCCIO = 1.8V for the neuropix interface.
FPGA
South-East
East
South-West
West
North-West
North
North-East
Analog Ref - Internal VREF = 3.3V
NB: Programming interface
NB: 0.1 is not needed.
NB:CLK0 drives PLL1.
IMU
I2C Selected
NB To get the best performance out of BNO055, it is recommended to use the external 32.768 kHz crystal.
3D TRACKING
NB: programmed to 93.6 MHz
NP POR Sequence 1. Digital 1.8V and 1.2V on 2. Wait 10 msec (handled by Osc EN kinda: it takes 1.3 msec) 3. Enable MCLK 4. Wait 10 MCLK cycles 5. NRST = 1 for 10 periods 6. NRSET = 0 to reset 7. Wait 200 msec 8. Power on 1.8 analog 9. Wait 1.8 ms 10. Power on 1.2 analog
NB: 1.8 msec delay
NB: Input cap serves both LDOs
NB: Needed on POR to get LOCK

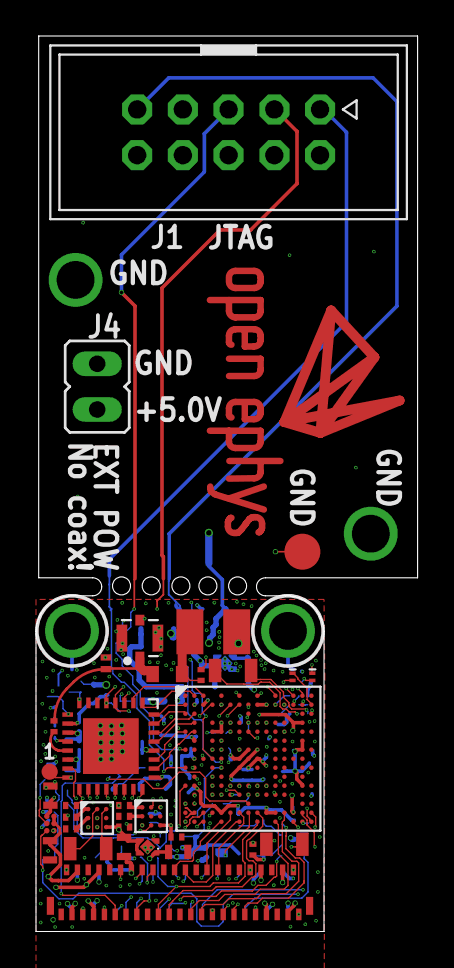
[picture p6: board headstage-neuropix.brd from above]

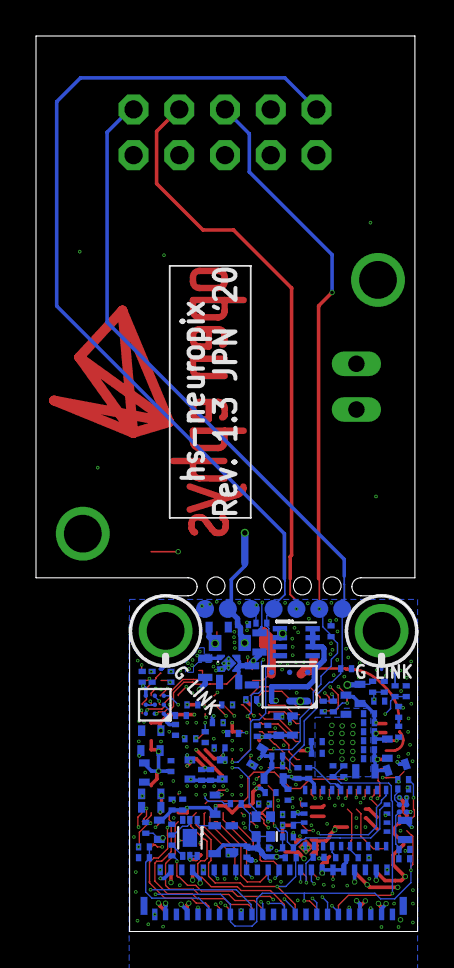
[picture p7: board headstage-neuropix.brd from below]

Board: 6 copper layers, 21.2 x 49.8 mm, 147 parts (112 on the bottom side), 121 nets.

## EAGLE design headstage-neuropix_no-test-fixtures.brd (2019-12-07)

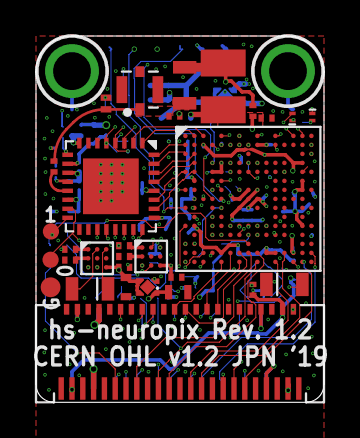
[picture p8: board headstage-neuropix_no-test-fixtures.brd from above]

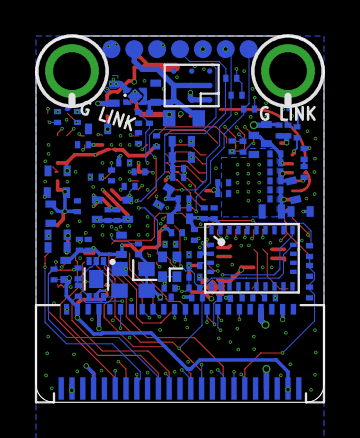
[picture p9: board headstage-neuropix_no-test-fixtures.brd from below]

Board: 6 copper layers, 16.0 x 20.4 mm, 127 parts (97 on the bottom side), 106 nets.

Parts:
C1, C2, C9, C10, C12, C13, C14, C15: 22nF; 0201T
C3, C4, C16, C17, C18, C19, C24, C28, C29, C30, C31, C39, C40, C41, C43, C53, C71, C75: 0.1uF; 0201T
C5, C6, C45, C46, C52: 4.7uF; 0402T
C7, C8, C20, C21, C22, C23, C35: 10uF; 0402T
C11, C25, C32, C33, C36, C37, C38, C49: 10nF; 0201T
C26, C27: 1uF; 0402T
C34, C47: 15uF; 0402TW
C44: 47nF; 0201T
C50: 0.33nF; 0201T
C72, C76: 1uF; 0201T
D1, D2: XZVGR155W; LED-0201T
D3: SESD0402X1UN-0020-090; 0402T-DFN
D9, D10: VEMD1160X01; 0805PT
J3, J7: FH23-45S-0.3SHW(05)
J5: X.FL-R-SMT-1(02); X_FL_R_SMT_1(02)
L1, L2, L3, L4, L5, L6, L7: BLM15PX601SN1D; 0402T
L8: BLM18KG601SN1D; 0603T
L9: CBC3225T101MR; 1210T
L10: CIG21L4R7MNE; 0805T
R1, R6: 2k; 0201T
R2, R3, R9, R10, R26, R27, R28, R29: 4.7k; 0201T
R4, R5, R8, R11, R12, R13, R14, R15, R16, R17, R19: 10k; 0201T
R7, R24, R25: 1k; 0201T
R18: 49.9; 0201T
R20: 100k; 0201T
R21, R30: 22; 0201T
R22: 20k; 0201T
R23: 100; 0201T
R48: 9k, 0.1%; 0201T
R51: 1k, 0.1%; 0201T
R86, R90: 15k; 0201T
TP1, TP2, TP3, TP4, TP5, TP6, TP7: TP10R
TP8: TP11R
TP10, TP11: TP09R
U1: 10M08SAM15317G; MBGA153-8X8
U2: ASCO2-24.000MHZ-EK-T3; ASCO
U3: TPS8268180; MICROSIP9-3X2.3
U4: TLV70712; X2SON
U5: TLV70733; X2SON
U6: BNO055; LGA-28-3.8X5.2
U7: DS90UB913A_WQFN; WQFN32-5X5
U8: 500SJAE93M6000ACF; SIT8008BCA7-18E
U9: PL133-27GC-R; DFN6_2X1.3_PAD
U25, U27: TS4231; WLCSP3X3

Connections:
24MHZ_P: U1.J5, U2.3
!IMU_BL: R16.2, U6.4
!IMU_RESET: R15.1, U6.11
+1V2: C34.1, J3.7, J3.8, J3.38, J3.39, J7.7, J7.8, J7.38, J7.39, U4.1
+1V8: C25.2, C30.1, C32.1, C37.1, C40.1, C46.1, C49.2, J3.3, J3.4, J3.42, J3.43, J7.3, J7.4, J7.42, J7.43, L4.1, L6.1, L7.1, R19.1, R26.2, R27.2, R28.2, R29.2, U3.A1, U3.A2, U7.11, U7.28, U8.1, U8.4, U9.5
+3V3: C2.1, C4.1, C6.1, C8.1, C11.2, C24.1, C26.1, C28.1, C31.1, C33.1, C35.1, C71.1, C75.1, L1.1, L2.1, L3.1, L5.1, R1.1, R2.2, R3.2, R4.1, R5.1, R6.1, R8.1, R9.2, R10.2, R12.1, R13.1, R14.1, R15.2, R16.1, R17.1, TP6.TP, U1.G8, U1.H7, U1.H9, U1.J8, U2.1, U2.4, U4.3, U4.4, U5.1, U6.3, U6.28, U7.25, U25.C3, U27.C3
BNO_SCL: R2.1, U1.L1, U6.19
BNO_SDA: R3.1, U1.K2, U6.20
CAL_1.3KHZ: R22.1, U1.N8
CAL_SIGNAL: C50.2, J3.11, J7.11, R22.2, R23.1
CONFIG_SEL: R11.1, U1.D8
CONF_DONE: R14.2, U1.E6
DIN0: U1.A5, U7.19
DIN1: U1.B8, U7.20
DIN2: U1.B4, U7.21
DIN3: U1.B6, U7.22
DIN4: U1.B7, U7.23
DIN5: U1.B11, U7.24
DIN6: U1.E2, U7.26
DIN7: U1.E1, U7.27
DIN8: U1.D2, U7.29
DIN9: U1.C2, U7.30
DIN10: U1.C1, U7.31
DIN11: U1.B1, U7.32
GND: C1.2, C2.2, C3.2, C4.2, C5.2, C6.2, C7.2, C8.2, C9.2, C10.2, C11.1, C12.2, C13.2, C14.2, C15.2, C16.2, C17.2, C18.2, C19.2, C20.2, C21.2, C22.2, C23.2, C24.2, C25.1, C26.2, C27.2, C28.2, C29.1, C30.2, C31.2, C32.2, C33.2, C34.2, C35.2, C36.2, C37.2, C38.2, C39.2, C40.2, C41.2, C45.2, C46.2, C47.2, C49.1, C50.1, C52.2, C53.2, C71.2, C72.2, C75.2, C76.2, D3.A, J3.1, J3.2, J3.5, J3.6, J3.9, J3.10, J3.13, J3.14, J3.17, J3.20, J3.23, J3.26, J3.29, J3.32, J3.34, J3.36, J3.37, J3.41, J3.44, J3.45, J5.P$2, J5.P$3, J5.P$4, J7.1, J7.2, J7.5, J7.6, J7.9, J7.10, J7.13, J7.14, J7.17, J7.20, J7.23, J7.26, J7.29, J7.32, J7.34, J7.36, J7.37, J7.41, J7.44, J7.45, R7.2, R11.2, R18.1, R20.2, R23.2, R51.1, R86.1, R90.1, TP7.TP, TP8.TP, U1.A1, U1.A15, U1.B2, U1.D5, U1.D9, U1.E4, U1.E5, U1.E12, U1.G4, U1.G9, U1.H8, U1.H14, U1.J7, U1.L12, U1.M2, U1.M6, U1.M10, U1.N1, U1.P2, U1.R1, U1.R15, U2.2, U3.C1, U3.C2, U3.C3, U4.2, U4.PAD, U5.2, U5.PAD, U6.2, U6.5, U6.6, U6.15, U6.16, U6.17, U6.18, U6.25, U7.6, U7.7, U7.PAD, U8.2, U9.3, U25.B2, U25.B3, U27.B2, U27.B3
HSYNC: U1.A2, U7.1
I2C_SCL_A: J3.19, R27.1, U1.R9
I2C_SCL_B: J7.19, R29.1, U1.R14
I2C_SDA_A: J3.18, R26.1, U1.L6
I2C_SDA_B: J7.18, R28.1, U1.M8
JTAGEN: R4.2, U1.G7
LH_DATA1: U1.H3, U25.C1
LH_DATA2: U1.G5, U27.C1
LH_ENV1: U1.J2, U25.C2
LH_ENV2: U1.F5, U27.C2
MIDFILT: L9.1, L10.2, R24.1, R25.2
unnamed: U8.3, U9.1, U9.6
unnamed: R30.1, U9.4
unnamed: J3.35, R21.2
unnamed: C13.1, C17.1, C20.1, L3.2, U1.H2
unnamed: J7.35, R30.2
unnamed: R21.1, U9.2
unnamed: D10.C, U25.A3
unnamed: D10.A, U25.A2
unnamed: R86.2, U25.B1
unnamed: C72.1, U25.A1
unnamed: C52.1, C53.1, L8.1, L9.2, R24.2
unnamed: D9.C, U27.A3
unnamed: D9.A, U27.A2
unnamed: R90.2, U27.B1
unnamed: C43.2, U7.13
unnamed: R17.2, U7.9
unnamed: C44.2, U7.12
unnamed: C44.1, R18.2
unnamed: R19.2, R20.1, U7.8
unnamed: C36.1, C39.1, C45.1, L6.2, U7.10
unnamed: C38.1, C41.1, C47.1, L7.2, U7.14
unnamed: C76.1, U27.A1
unnamed: R48.2, R51.2, U1.D4
unnamed: C29.2, U6.9
unnamed: D2.2, R6.2
unnamed: D1.2, R1.2
NCONFIG: R12.2, U1.E8
NRST_A: J3.15, U1.P8
NRST_B: J7.15, U1.P15
NSTATUS: R13.2, U1.D6
OSC_PDOWN_N_A: J3.12, U1.P3
OSC_PDOWN_N_B: J7.12, U1.L10
PCLK: U1.A11, U7.3
PSB_CLK_A: J3.33, U1.K4
PSB_CLK_B: J7.33, U1.L4
PSB_DATA_0_A: J3.31, U1.R13
PSB_DATA_0_B: J7.31, U1.M7
PSB_DATA_1_A: J3.30, U1.R7
PSB_DATA_1_B: J7.30, U1.M4
PSB_DATA_2_A: J3.28, U1.P6
PSB_DATA_2_B: J7.28, U1.P4
PSB_DATA_3_A: J3.27, U1.P12
PSB_DATA_3_B: J7.27, U1.L8
PSB_DATA_4_A: J3.25, U1.R11
PSB_DATA_4_B: J7.25, U1.L9
PSB_DATA_5_A: J3.24, U1.P7
PSB_DATA_5_B: J7.24, U1.M5
PSB_DATA_6_A: J3.22, U1.R5
PSB_DATA_6_B: J7.22, U1.L7
PSB_SYNC_A: J3.21, U1.P9
PSB_SYNC_B: J7.21, U1.M11
REC_NRST_A: J3.16, U1.R3
REC_NRST_B: J7.16, U1.M9
SERDES_GPIO0: TP11.TP, U1.A7, U7.15
SERDES_GPIO1: TP10.TP, U1.A9, U7.16
SERDES_SCL: R9.1, U1.A13, U7.4
SERDES_SDA: R10.1, U1.A14, U7.5
SIGOUT: C43.1, D3.C, J5.P$1, L10.1, R25.1
STATUS_A: D1.1, U1.C15
STATUS_B: D2.1, U1.B15
TCK: R7.1, TP3.TP, U1.J1
TDI: R8.2, TP4.TP, U1.H5
TDO: TP5.TP, U1.H4
TMS: R5.2, TP2.TP, U1.G1
VCCA: C1.1, C3.1, C5.1, C7.1, L1.2, U1.B3, U1.D14, U1.N2, U1.P13
VCCIO: C10.1, C15.1, C19.1, C22.1, L5.2, U1.B5, U1.B9, U1.B10, U1.F14, U1.G14, U1.L14
VCCIO2: C9.1, C14.1, C18.1, C21.1, L4.2, U1.L2, U1.P5, U1.P10, U1.P11
VCCIOA: C12.1, C16.1, C23.1, L2.2, U1.F2
VCOAX: C27.1, L8.2, R48.1, TP1.TP, U3.A3, U3.B1, U3.B2, U3.B3, U5.3, U5.4
VSYNC: U1.A3, U7.2

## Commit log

2019-08-08 Initial rough component placement for neuropix test headstage
    [headstage-neuropix-64.brd, headstage-neuropix-64.sch]
2019-08-08 Added ZIF conn and did some basic layout
    Hirose FH23-45S-0.3SHW(05) ( HFQ645CT-ND ) looks like it will work
    [headstage-neuropix-64.brd, headstage-neuropix-64.sch]
2019-08-09 Added LMK61E2
    Should solve the issue of how to make 93.6 MHz, but is pretty huge
    [headstage-neuropix-64.brd, headstage-neuropix-64.sch]
2019-08-10 Some more layout on neuropix headstage
    - Switched to large MAX10
    - started to assign some pins
    [headstage-neuropix-64.brd, headstage-neuropix-64.sch]
2019-08-12 Cleaned up and renamed neuropix headstage
    [headstage-neuropix.brd, headstage-neuropix.sch]
2019-08-12 Moved some things on the neuropix HS
    jon take over
    [headstage-neuropix.brd, headstage-neuropix.sch]
2019-08-15 headstage-neuropix rev 1.0
    - Should conform to JLCPCB 6-layer DRU
    [headstage-neuropix.GBL, headstage-neuropix.GBO, headstage-neuropix.GBS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]
2019-08-18 Revisions to headstage-neuropix following group review
    - The programmable oscillator was removed because the MCLK signal is not
    needed by the FPGA. It was replaced with a factory programmed 93.6 MHz
    silicon oscillator that is feed directly into MCLK pin via RC low-pass
    filter that matches that on the IMEC headstage
    - Added the BNO055 IMU
    - Other small changes to silkscreen and debug routing (e.g. remove
    unnecessary copper planes from debug tabs to prevent shorting when they
    are removed)
    [headstage-neuropix.GBL, headstage-neuropix.GBO, headstage-neuropix.GBS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]
2019-08-19 Fixed flat-flex connector part number on headstage-neuropix
    - Also, updated PDF of schematic
    [headstage-neuropix.brd, headstage-neuropix.sch]
2019-09-27 headstage-neuropix rev. 1.1
    - Changes after testing rev. 1.0
    - Coax connection moved away from the inductors to give more wiggle room
    during connection
    - 1.2 Vreg now has Vin = 3.3V instead of 1.8, which was non functional
    - Pullups added to NP i2c lines
    - Bottom side debug ground connections added
    - Debug port inverted to match my logic analyzer pin direction
    - Silkscreen update
    [headstage-neuropix.GBL, headstage-neuropix.GBO, headstage-neuropix.GBS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]
2019-10-28 headstage-neuropix rev 1.2
    - Fix a couple issues found during assembly of revision 1.1
    - Move C and L pads containing 3.3V and GND further appart to prevent
    shorting during reflow
    - Add Vcoax measurement to FPGA's ADC
    - 0402 15 uF pads are wider by 0.2 mm
    - Move bypass caps further away from LDOs for ease of assembly
    [headstage-neuropix.brd, headstage-neuropix.sch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]
2019-12-07 headstage-neuropix rev 1.2
    - Dual neuropixels probe support
    - 2X HTC Vive receivers
    - Many changes made for reliability of manufacturing
    [headstage-neuropix.GBL, headstage-neuropix.GBS, headstage-neuropix.GKO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]
2020-02-27 Revision 1.2 of headstage-neuropix
    - Routed all GPIO from serializer to FPGA
    - Inner layers are now 3 mil trace space
    - via-reduce just like headstage-64
    [headstage-neuropix.brd, headstage-neuropix.sch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]
2020-03-09 Final headstage-neuropix rev. 1.2
    - BOM simplification while updating the google sheet
    - Small PCB changes
    [headstage-neuropix.brd, headstage-neuropix.sch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]
2020-05-22 Added third lighthouse receiver to headstage-neuropix
    - I'm now sending this to speedy for a quote
    [headstage-neuropix.brd, headstage-neuropix.sch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]
2020-05-30 Minor improvements to headstage-neuropix rev 1.2
    - Final changes before production
    - Minor BOM simplification
    [headstage-neuropix.brd, headstage-neuropix.sch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]
2020-06-02 More updates to headstage-neuropix after review from Speedy
    - Many bottom side pads moved apart to allow solder mask in between and
    to prevent shorts
    [headstage-neuropix.brd, headstage-neuropix.sch, headstage-neuropix_via-reduce.brd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]
2021-02-15 headstage-neuropix rev. 1.3
    - Fixes several issues found during testing or revision 1.2
    - Analog power to neurpixels probe is now isolated using LC filter from
    digital power
    - 93.6 MHz osc gets power from 1.8V instead of 3.3. Footprint fixed.
    - Vcoax has more bulk capacitance now
    - Serializer has capacitance on its PDN pin as recormmended to get POR
    sequence correct
    - I added a UVLO OVLO circuit between the DC filter on coax input and
    all the regulators powering the board. The headstage will only operate
    in a ~4.1-6.5 volt window.
    [headstage-neuropix.brd, headstage-neuropix.sch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]
2021-05-29 headstage-neuropix rev. 1.3
    - Addresses several more issues encountered during extensive testing of
    rev. 1.2
    - Analog rails of probes provided by dedicated LDOs that respect the
    complex POR sequence required by the probes
    - The clock enable for the dual clock buffer for each probe is tied high
    instead of being driven by the clock input (!)
    - Each probe has a dedicated calibration signal
    [headstage-neuropix.brd, headstage-neuropix.sch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]
2021-05-29 Standard ZIF version of headstage-neuropix rev 1.3
    - Added a second version of the headstage that uses the smaller,
    IMEC-specified ZIF connector
    - Reorganized the folder a bit to support this change
    [headstage-neuropix.brd, headstage-neuropix.sch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]
2021-05-30 Updated BOM for revision 1.3
    - External on google-sheet. Link added to READMEs for each board
    version.
    - Schematics updated to reflect the BOM.
    - Added SMD mount information
    - Added .gitignore and .gitattributes for LFS
    [headstage-neuropix.brd, headstage-neuropix.sch]
2021-05-30 Moved X.FL coax connector up 0.5 mm following OEPS feedback
    - Allows more tolerance for passives under it
    - Did this for both headstage variants
    [headstage-neuropix.brd, headstage-neuropix_via-reduce.brd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]
2021-07-28 Small layout changes after communicating with Speedy
    - Reduced solder mask openings a bit
    - Other small changes
    [headstage-neuropix.brd, headstage-neuropix.sch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]
2021-08-05 Correct tPlace/tStop mixup for ADP7112's
    - Solder pads had tPlace instead of tStop so there would have been
    silkscreen on the pads
    [headstage-neuropix.brd, headstage-neuropix.sch, headstage-neuropix_via-reduce.brd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]
2021-08-09 Revision 1.3
    - Update SMD mount files for produced design
    - Add the production files provided by speedy to the repository
2021-08-09 Repository reorganization
    - Moved all design files into the headstage-neuropix1 directory
    - Added image of rev 1.2 with probes attached
    [headstage-neuropix.brd, headstage-neuropix.sch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]
2021-08-10 Added stencil gerbers to production files.
    [headstage-neuropix.brd, headstage-neuropix.sch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]

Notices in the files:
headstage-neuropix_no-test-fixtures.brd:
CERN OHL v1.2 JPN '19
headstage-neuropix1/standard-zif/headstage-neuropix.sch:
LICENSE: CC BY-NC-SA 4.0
